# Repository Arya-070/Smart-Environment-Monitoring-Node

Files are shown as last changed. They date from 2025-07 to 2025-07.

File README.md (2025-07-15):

# 🌿 Smart Environment Monitoring Node  
📡 ESP32-WROOM-32 + LoRa + BME280 + OLED | USB Powered | Custom PCB

──────────────────────────────────────────────

## 📌 Overview

This project is a compact, power-efficient, and long-range **environment monitoring system** based on the **ESP32-WROOM-32 chip**. It measures temperature, humidity, and pressure using the **BME280 sensor**, displays real-time values on a **0.96” OLED display**, and transmits the data via **LoRa SX1262** for remote monitoring.  

All hardware is designed on a **custom 2-layer PCB** and powered via a **USB Micro-B port**, with built-in USB-to-Serial conversion and auto-upload support for seamless firmware flashing.

---

## ✨ Project Highlights

• 🔧 Fully custom-designed PCB (2-layer) using KiCad  
• 📡 Long-range LoRa communication using SX1262  
• 🌡 Environmental monitoring using BME280  
• 🖥 Local data display via 0.96” I2C OLED  
• 🔌 USB-powered with CH340C USB-to-Serial interface  
• ⏩ Auto-upload circuit using NPN transistors  
• 🔁 Reset + Boot buttons like ESP32 Dev board  
• 📍Test points for VCC & GND for easy debugging  
• 🔋 AMS1117-based 3.3V regulator (if needed)  

---

## 📌  ESP32 GPIO Pinout & Connections 

| GPIO Pin | Connected To | Function / Role |
|---|---|---|
| GPIO 0 | Q2 (Transistor) | BOOT (Auto Upload via DTR) |
| GPIO 1 (TXD)| CH340C RXD | UART Transmission |
| GPIO 3 (RXD)| CH340C TXD | UART Reception |
| GPIO 4 | SX1262 NSS | SPI Chip Select (LoRa) |
| GPIO 5 | SX1262 BUSY | LoRa Busy Status |
| GPIO 14 | SX1262 SCK | SPI Clock |
| GPIO 18 | SX1262 MISO | SPI MISO |
| GPIO 19 | SX1262 MOSI | SPI MOSI |
| GPIO 21 | OLED SDA | I2C Data (Display) |
| GPIO 22 | OLED SCL | I2C Clock (Display) |
| GPIO EN | Q1 (Transistor) | EN (Auto Reset via RTS) |
| GPIO 23 | SX1262 DIO1 | LoRa Interrupt |
| GPIO 16 | SX1262 DIO2 | LoRa General-Purpose I/O |
| GPIO 17 | BME280 SCK | SPI Clock (Sensor) |
| GPIO 2 | LED (Optional) | Debug LED Output |
| GPIO 13 | SX1262 NSS (2nd) | SPI Slave Select (Alt, Unused?) |
| GPIO 12,15 | — | Reserved / Available for future use |

🔍 *See schematic for exact net labels and detailed mapping.*

---

## 🔍 Use Case Acknowledgement

This project is ideal for:

• Agricultural field condition monitoring  
• Weather stations (indoor or outdoor)  
• Smart home environmental logging  
• Educational IoT demonstrations  
• Smart city sensor node deployment  
• Remote sensing with LoRa infrastructure

---

## 🧭 System Architecture

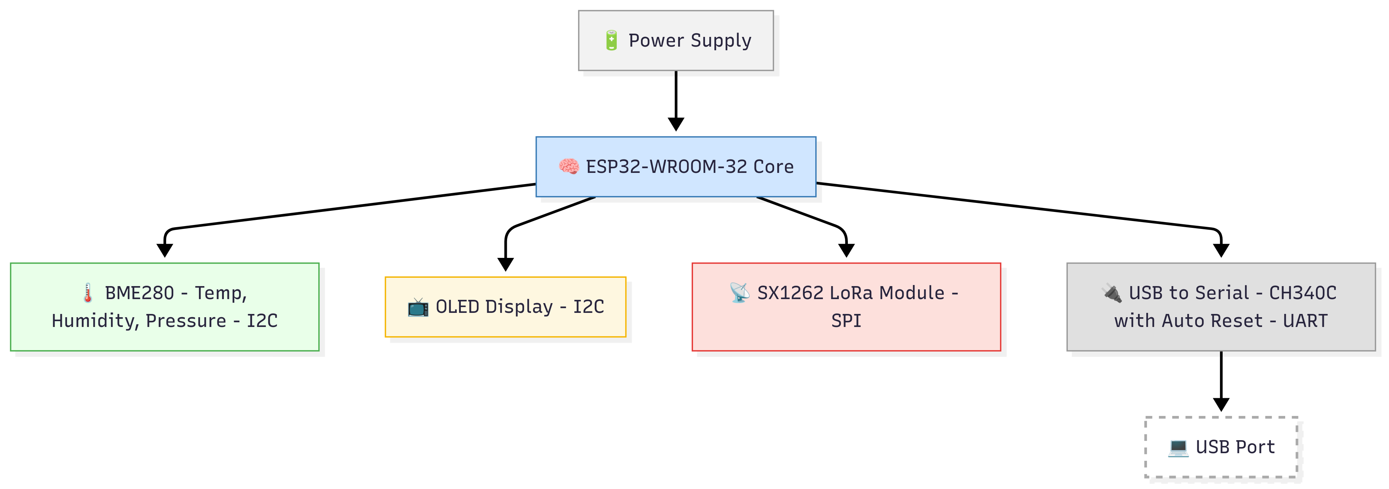
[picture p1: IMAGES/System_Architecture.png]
System Architecture


---

## 🧩 Component Summary

| No. | Component | Interface | Description |
|-----|---|---|---|
| 1 | ESP32-WROOM-32 | - | Main MCU (WiFi, BLE, Dual Core) |
| 2 | BME280 (SPI) | SPI | Temp, Pressure, Humidity sensor |
| 3 | OLED 0.96” Display | I2C | SSD1306, 128x64 pixel display |
| 4 | SX1262IMLTRT (QFN) | SPI | LoRa transceiver (433/868/915MHz) |
| 5 | AMS1117-3.3V Regulator | Power | Converts 5V USB to 3.3V (optional) |
| 6 | CH340C USB to Serial | UART | USB programming interface |
| 7 | 40MHz Crystal Oscillator| CLK | ESP32 clock source |
| 8 | Push Buttons (2x) | GPIO/EN | Boot and Reset functionality |
| 9 | LED + Resistor | Power | Power-on indicator |
| 10  | Capacitors (0.1µF, 10µF)| Power | Decoupling & filtering |
| 11  | Test Points (TP1/TP2)  | - | For debugging (3.3V and GND) |
| 12  | Micro USB Port | Power | Power + Serial communication |
| 13  | Resistors (10k, 1k) | Logic | Pull-ups and transistor base resistors |
| 14  | NPN Transistors (x2) | Auto Upload | Connected to DTR/RTS |
| 15  | Conn_01x2 / 01x4 / 01x8| Header | GPIO/I2C/Power breakout (optional) |

---

## 💾 Firmware Summary

• Platform: Arduino Framework  
• Libraries:
  - `Adafruit_BME280` (SPI)
  - `U8g2lib` / `Adafruit_SSD1306`
  - `RadioLib` or `LoRa` for SX1262
• Logic:
  - Read sensor values → Display on OLED → Send via LoRa
• Auto-upload handled via CH340C + transistor toggling of IO0 and EN

---

## 🧪 Test Points

| Label | Connected To | Use |
|---|---|---|
| TP1 | 3.3V | Voltage test/debug |
| TP2 | GND | Ground continuity check |

---

## 📦 Folder Structure

```
Smart-Environment-Monitoring-Node/
│
├── SCHEMATIC/
│   ├── Smart_Env_monitoring_Node.kicad_sch
│   ├── Smart_Env_monitoring_Node.pdf
│  
├── Backup_ZIP
│
├── PCB/
│   ├──  Smart_Env_monitoring_Node.kicad_pcb
│   ├──  Smart_Env_monitoring_Node.kicad_pro
│   ├──  Smart_Env_monitoring_Node.csv
│   ├── Gerber_Files/
│   ├── F_Cu.gbr
│   ├── B_Cu.gbr
│   ├── Edge_Cuts.gbr
│   ├── Drill.drl
│   └── ...etc
│
├── Firmware/
│   └── main.ino 
│
├── Libraries/
│   ├── COMPONENTS_DOWNLOADED/
│   └── MY_LIBRARY_MODIFIED.pretty/
│
├── Images/
│   ├── 3D_View.png
│   ├── Top_Layout.png
│   ├── Bottom_Layout.png
│   └── System_Architecture.png
│
├── README.md
└── .gitignore
```

---

## 📐 PCB Design Summary

• Software: KiCad 7.0  
• Layers: 2 (Top & Bottom)  
• Antenna zone: Keep-out area maintained  
• Crystal zone: No trace below (as per layout best practices)  
• Ground pour: Yes, with via stitching  
• Auto-upload near CH340C  
• I2C lines shared between OLED and future I2C sensors

---

## 📌 Optional Headers

| Header | Size | Description |
|---|---|---|
| Conn_01x2  | 2-pin | External battery connection |
| Conn_01x4  | 4-pin | I2C expansion header |
| Conn_01x8  | 8-pin | GPIO access (debug/expansion) |

---

## 🔮 Future Improvements

• Add onboard Li-ion battery charging (TP4056)  
• Use low-dropout regulator instead of AMS1117  
• Enable I2C/SPI switch for BME280  
• Add buzzer or notification LED  
• Add deep sleep mode for power efficiency  
• Add mobile enclosure + mounting holes

---

## 📜 License

Licensed under the MIT License.  
Feel free to use, modify, and share — just give credit. 

---

## 🤝 Acknowledgements

This project is inspired by real-world smart sensing requirements and open hardware communities. Thanks to Espressif Systems, Adafruit, and the KiCad team for empowering makers with tools and documentation.

---

## 📬 Contact / Contribution

• Found something useful? Leave a ⭐ on GitHub.  
• Found a bug or want to improve? Fork and PRs are welcome.  
• Reach out for collaboration or questions!

Let’s make sensing smarter, together. 🌍

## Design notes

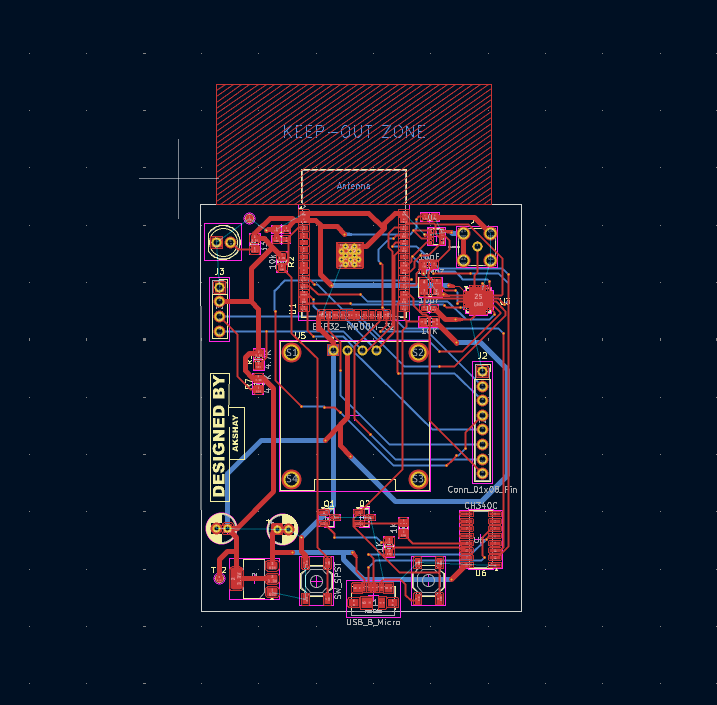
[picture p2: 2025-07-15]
IMAGES/editor-view.png

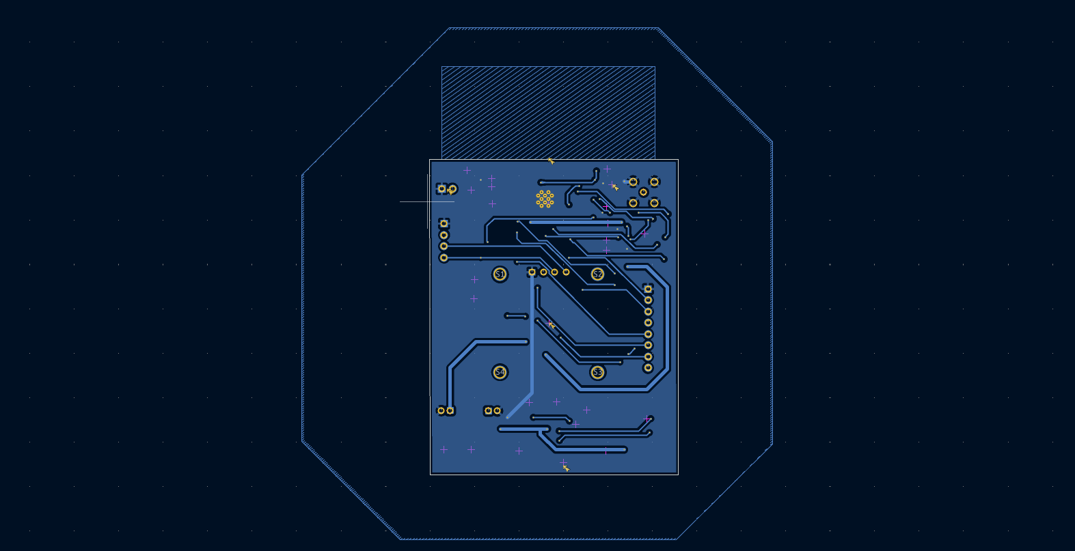
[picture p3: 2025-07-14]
IMAGES/Bottom_Layout.png

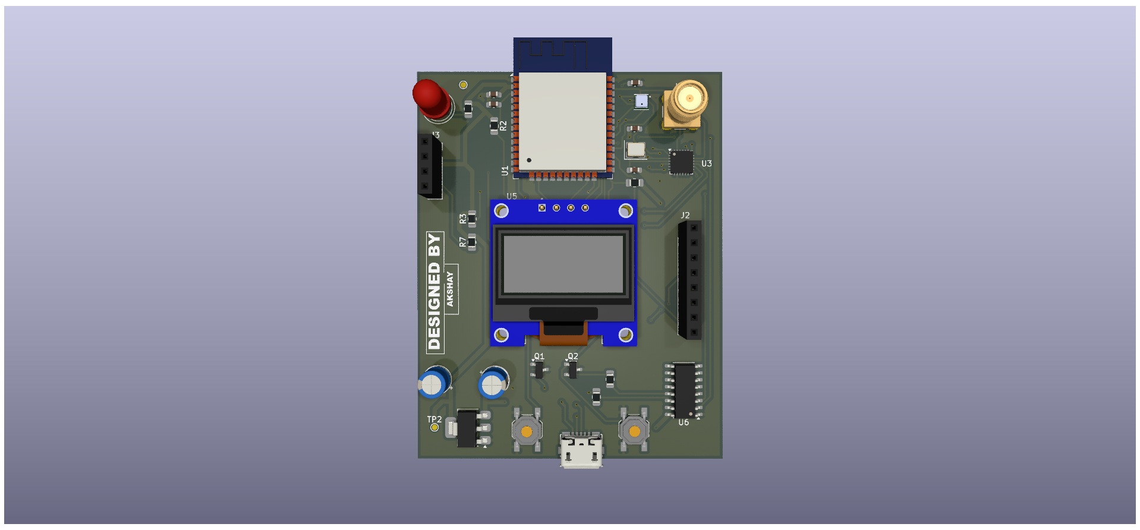
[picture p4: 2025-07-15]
IMAGES/3d-View.png

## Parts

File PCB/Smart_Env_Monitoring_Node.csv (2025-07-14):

Reference | Qty | Value | DNP | Exclude from BOM | Exclude from Board | Footprint | Datasheet
C1,C2 | 2 | 10uF |  |  |  | Capacitor_THT:CP_Radial_D5.0mm_P2.00mm | ~
C3,C4,C5 | 3 | 0.1uF |  |  |  | Capacitor_SMD:C_0603_1608Metric_Pad1.08x0.95mm_HandSolder | ~
C6,C7 | 2 | 10pF |  |  |  | Capacitor_SMD:C_0603_1608Metric_Pad1.08x0.95mm_HandSolder | ~
D1 | 1 | LED |  |  |  | MY_LIBRARY_MODIFIED:LED_D5.0mm_modified | ~
J1 | 1 | USB_B_Micro |  |  |  | MY_LIBRARY_MODIFIED:USB_Micro-B_Molex_47346-0001 | ~
J2 | 1 | Conn_01x08_Pin |  |  |  | Connector_PinSocket_2.54mm:PinSocket_1x08_P2.54mm_Vertical | ~
J3 | 1 | Conn_01x04_Pin |  |  |  | Connector_PinSocket_2.54mm:PinSocket_1x04_P2.54mm_Vertical | ~
J4 | 1 | SMA_CONNECTOR |  |  |  | SMA_FEMALE:LPRS_SMA_CONNECTOR
Q1,Q2 | 2 | BC547 |  |  |  | Package_TO_SOT_SMD:SOT-23 | ~
R1 | 1 | 10K |  |  |  | Resistor_SMD:R_0805_2012Metric_Pad1.20x1.40mm_HandSolder | ~
R2 | 1 | 10k |  |  |  | Resistor_SMD:R_0805_2012Metric_Pad1.20x1.40mm_HandSolder | ~
R3,R7 | 2 | 4.7K |  |  |  | Resistor_SMD:R_0805_2012Metric_Pad1.20x1.40mm_HandSolder | ~
R4 | 1 | 330 |  |  |  | Resistor_SMD:R_0805_2012Metric_Pad1.20x1.40mm_HandSolder | ~
R5,R6 | 2 | 1K |  |  |  | Resistor_SMD:R_0805_2012Metric_Pad1.20x1.40mm_HandSolder | ~
SW2,SW3 | 2 | SW_SPST |  |  |  | Button_Switch_SMD:SW_SPST_TL3342 | ~
TP1,TP2 | 2 | TestPoint |  |  |  | TestPoint:TestPoint_Pad_D1.0mm | ~
U1 | 1 | ESP32-WROOM-32 |  |  |  | MY_LIBRARY_MODIFIED:ESP32-WROOM-32_MODIFIED | https://www.espressif.com/sites/default/files/documentation/esp32-wroom-32_datasheet_en.pdf
U2 | 1 | AMS1117-3.3 |  |  |  | Package_TO_SOT_SMD:SOT-223-3_TabPin2 | http://www.advanced-monolithic.com/pdf/ds1117.pdf
U3 | 1 | SX1262IMLTRT |  |  |  | Package_DFN_QFN:QFN-24-1EP_4x4mm_P0.5mm_EP2.6x2.6mm | https://semtech.file.force.com/sfc/dist/version/download/?oid=00DE0000000JelG&ids=0682R00000IjPWSQA3
U4 | 1 | BME280 |  |  |  | BME280:PSON65P250X250X100-8N
U5 | 1 | DM-OLED096-636 |  |  |  | DM-OLED096-636:MODULE_DM-OLED096-636
U6 | 1 | CH340C |  |  |  | Package_SO:SOIC-16_3.9x9.9mm_P1.27mm | https://datasheet.lcsc.com/szlcsc/Jiangsu-Qin-Heng-CH340C_C84681.pdf
Y1 | 1 | 16Mhz |  |  |  | Crystal:Crystal_SMD_3225-4Pin_3.2x2.5mm | ~

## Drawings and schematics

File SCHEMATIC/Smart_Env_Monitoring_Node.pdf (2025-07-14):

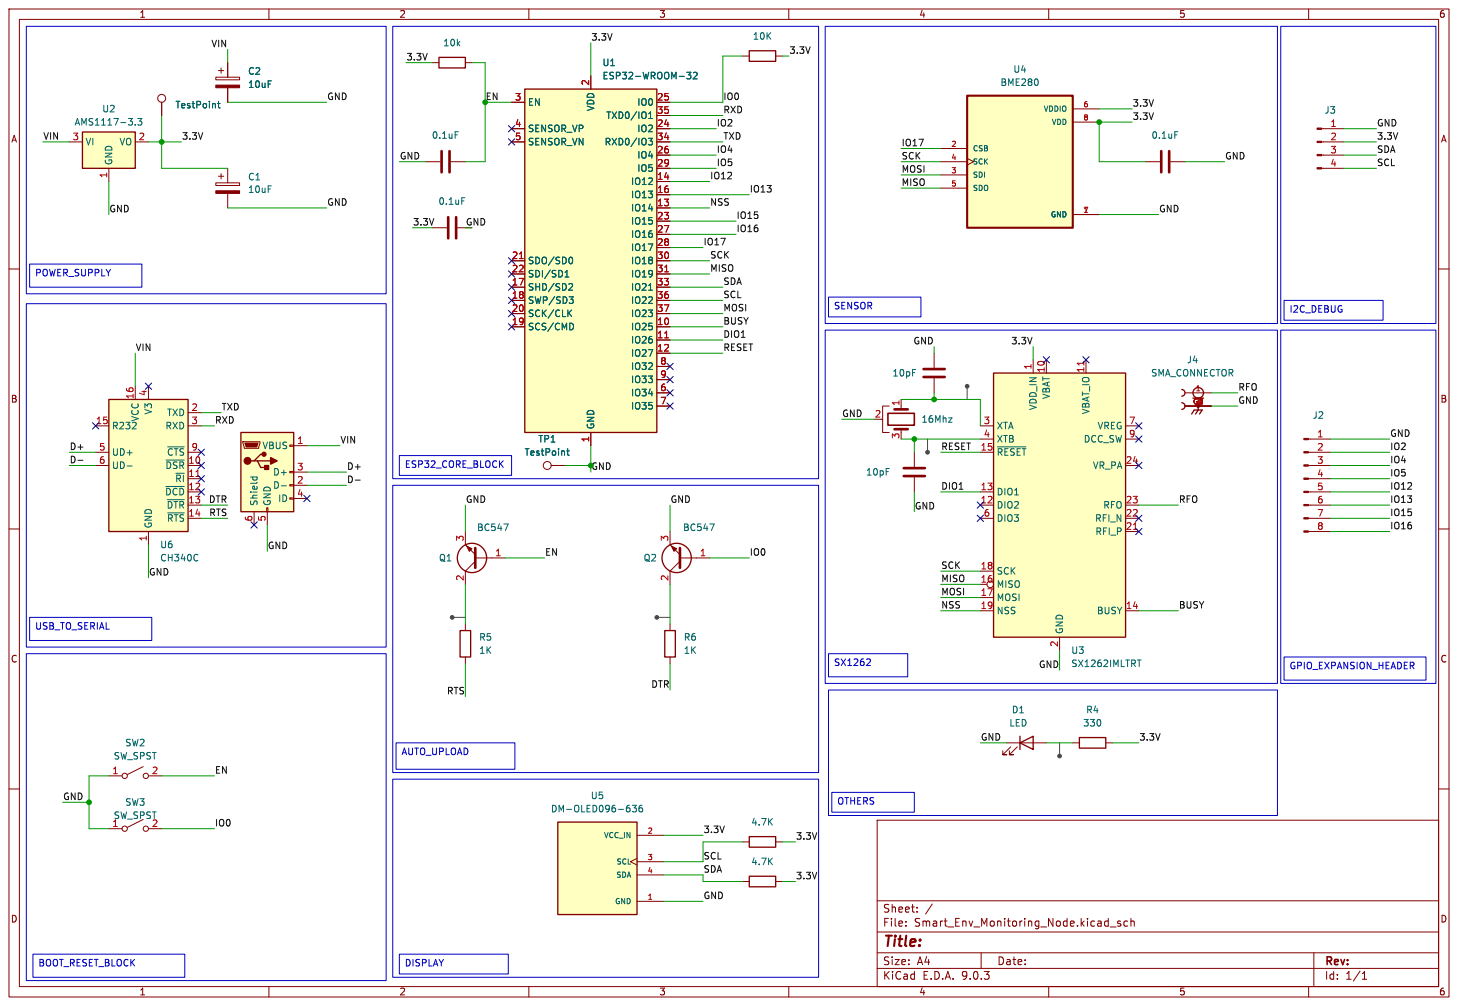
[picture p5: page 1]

1 TXD 2 RXD 3 ~{CTS}9 ~{DSR} 10 ~{RI} 11 ~{DCD} 12 ~{DTR} 13 ~{RTS} 14 U6 CH340C Shield

Id: 1/1 Title: File: Smart_Env_Monitoring_Node.kicad_sch Sheet: /

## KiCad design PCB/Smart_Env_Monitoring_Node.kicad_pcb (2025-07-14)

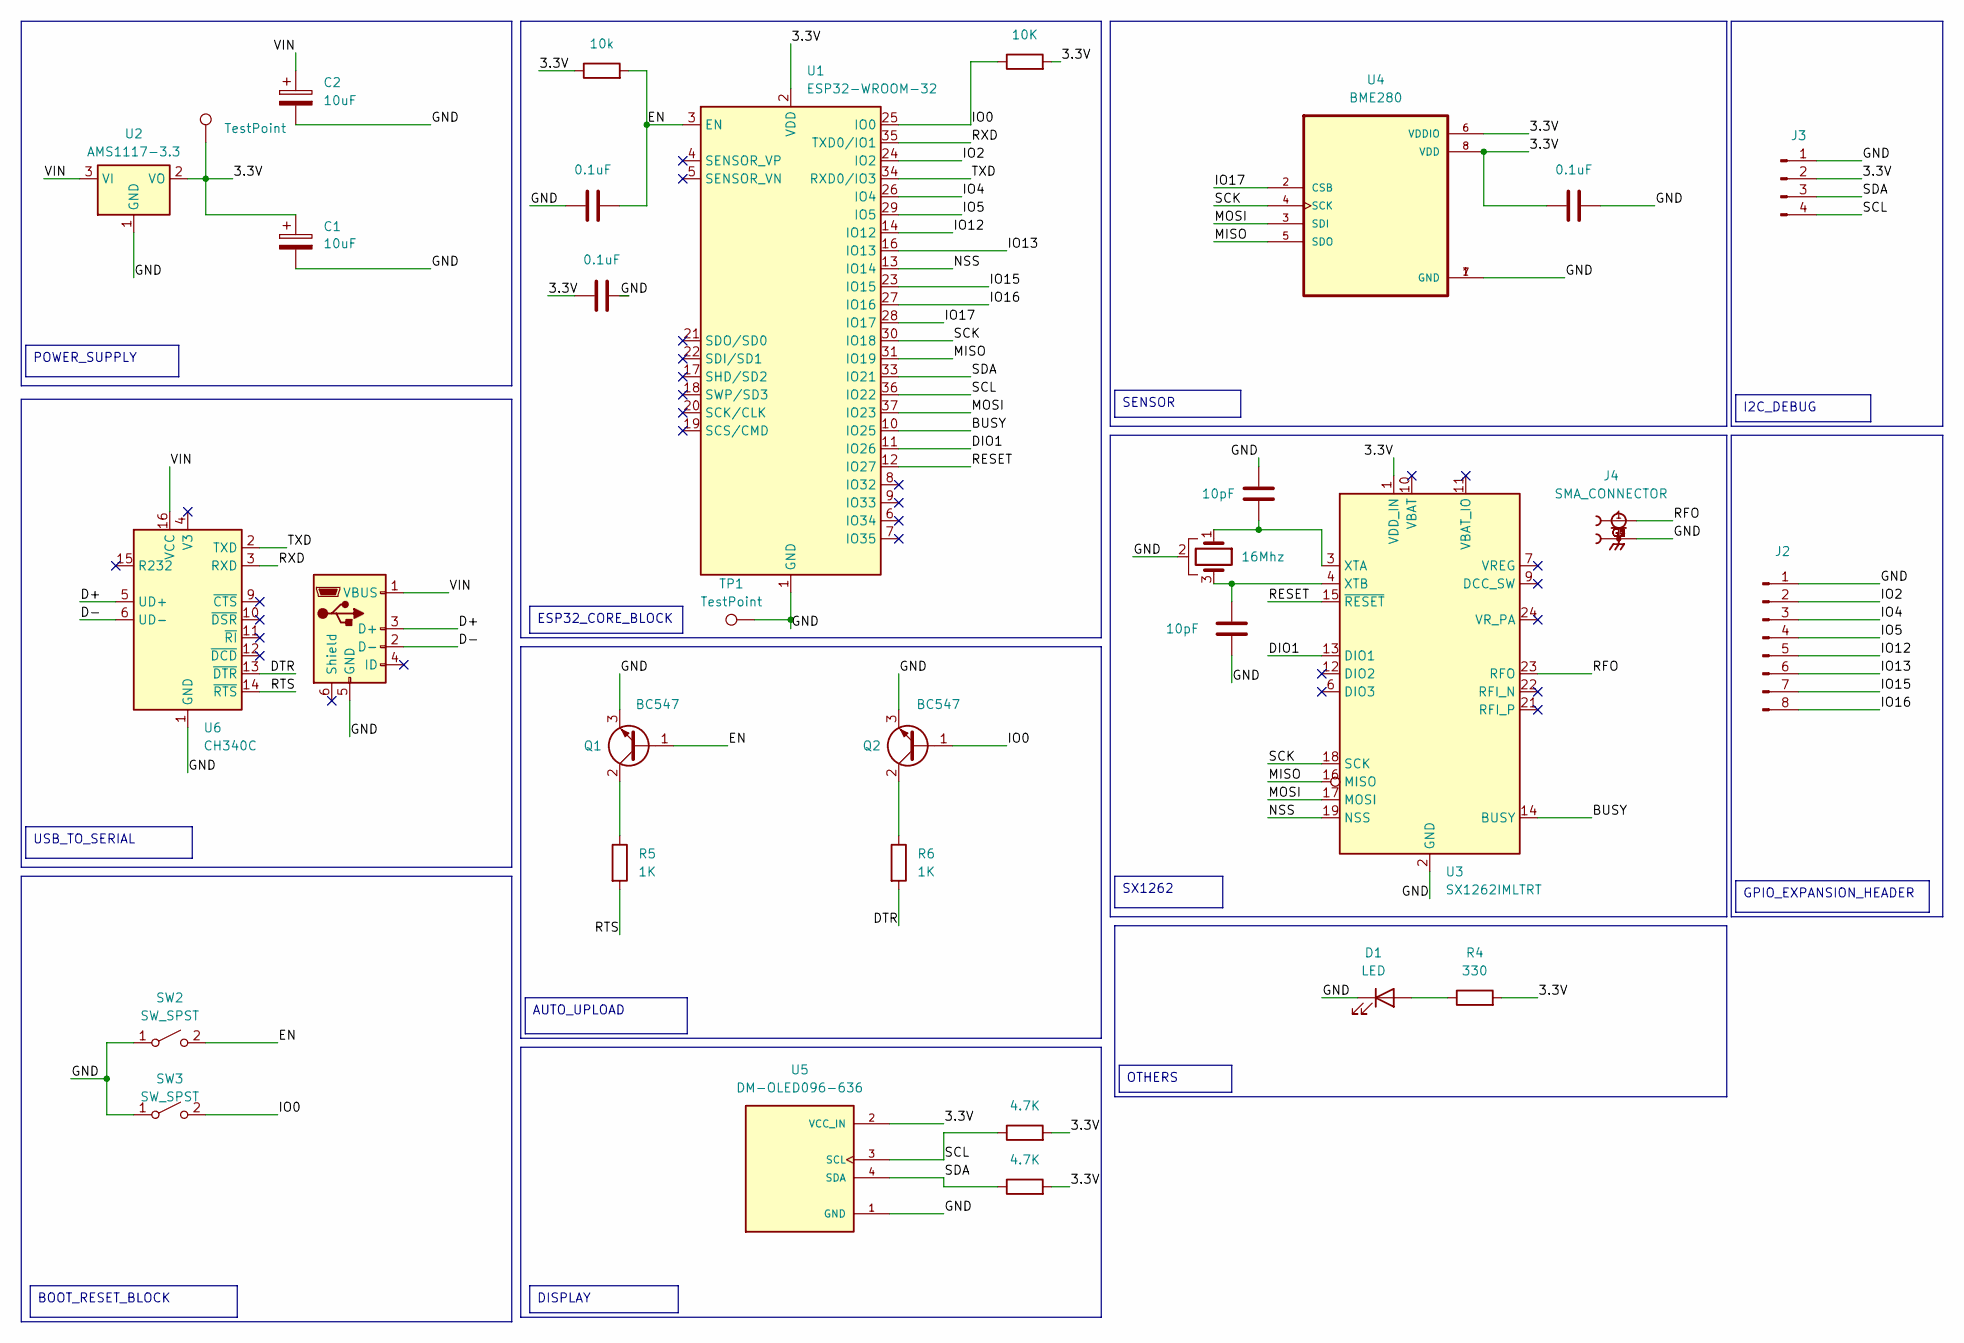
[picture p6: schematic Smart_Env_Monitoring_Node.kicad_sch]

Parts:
C1, C2: 10uF; CP_Radial_D5.0mm_P2.00mm
C3, C4, C5: 0.1uF; C_0603_1608Metric_Pad1.08x0.95mm_HandSolder
C6, C7: 10pF; C_0603_1608Metric_Pad1.08x0.95mm_HandSolder
D1: LED; LED_D5.0mm_modified
J1: USB_B_Micro; USB_Micro-B_Molex_47346-0001
J2: Conn_01x08_Pin; PinSocket_1x08_P2.54mm_Vertical
J3: Conn_01x04_Pin; PinSocket_1x04_P2.54mm_Vertical
J4: SMA_CONNECTOR; LPRS_SMA_CONNECTOR; PARTREV 1.3
Q1, Q2: BC547; SOT-23
R1: 10K; R_0805_2012Metric_Pad1.20x1.40mm_HandSolder
R2: 10k; R_0805_2012Metric_Pad1.20x1.40mm_HandSolder
R3, R7: 4.7K; R_0805_2012Metric_Pad1.20x1.40mm_HandSolder
R4: 330; R_0805_2012Metric_Pad1.20x1.40mm_HandSolder
R5, R6: 1K; R_0805_2012Metric_Pad1.20x1.40mm_HandSolder
SW2, SW3: SW_SPST; SW_SPST_TL3342
TP1, TP2: TestPoint; TestPoint_Pad_D1.0mm
U1: ESP32-WROOM-32; ESP32-WROOM-32_MODIFIED
U2: AMS1117-3.3; SOT-223-3_TabPin2
U3: SX1262IMLTRT; QFN-24-1EP_4x4mm_P0.5mm_EP2.6x2.6mm
U4: BME280; PSON65P250X250X100-8N
U5: DM-OLED096-636; MODULE_DM-OLED096-636; PARTREV 2018-09-10
U6: CH340C; SOIC-16_3.9x9.9mm_P1.27mm
Y1: 16Mhz; Crystal_SMD_3225-4Pin_3.2x2.5mm

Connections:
/3.3V: C1.1, C4.1, C5.1, J3.2, R1.2, R2.1, R3.2, R4.2, R7.2, TP2.1, U1.2 (VDD), U2.2 (VO), U3.1 (VDD_IN), U4.6 (VDDIO), U4.8 (VDD), U5.2 (VCC_IN)
/BUSY: U1.10 (IO25), U3.14 (BUSY)
/D+: J1.3 (D+), U6.5 (UD+)
/D-: J1.2 (D-), U6.6 (UD-)
/DIO1: U1.11 (IO26), U3.13 (DIO1)
/DTR: R6.2, U6.13 (~DTR)
/EN: C3.2, Q1.1 (B), R2.2, SW2.2 (B), U1.3 (EN)
/GND: C1.2, C2.2, C3.1, C4.2, C5.2, C6.1, C7.2, D1.1 (K), J1.5 (GND), J2.1, J3.1, J4.G1, J4.G2, J4.G3, J4.G4, Q1.3 (E), Q2.3 (E), SW2.1 (A), SW3.1 (A), TP1.1, U1.1 (GND), U1.15 (GND), U1.38 (GND), U1.39 (GND), U2.1 (GND), U3.2 (GND), U3.5 (GND), U3.8 (GND), U3.20 (GND), U3.25 (GND), U4.1 (GND), U4.7 (GND), U5.1 (GND), U6.1 (GND), Y1.2
/IO0: Q2.1 (B), R1.1, SW3.2 (B), U1.25 (IO0)
/IO2: J2.2, U1.24 (IO2)
/IO4: J2.3, U1.26 (IO4)
/IO5: J2.4, U1.29 (IO5)
/IO12: J2.5, U1.14 (IO12)
/IO13: J2.6, U1.16 (IO13)
/IO15: J2.7, U1.23 (IO15)
/IO16: J2.8, U1.27 (IO16)
/IO17: U1.28 (IO17), U4.2 (CSB)
/MISO: U1.31 (IO19), U3.16 (MISO), U4.5 (SDO)
/MOSI: U1.37 (IO23), U3.17 (MOSI), U4.3 (SDI)
/NSS: U1.13 (IO14), U3.19 (NSS)
/RESET: U1.12 (IO27), U3.15 (~RESET)
/RFO: J4.1, U3.23 (RFO)
/RTS: R5.2, U6.14 (~RTS)
/RXD: U1.35 (TXD0/IO1), U6.3 (RXD)
/SCK: U1.30 (IO18), U3.18 (SCK), U4.4 (SCK)
/SCL: J3.4, R3.1, U1.36 (IO22), U5.3 (SCL)
/SDA: J3.3, R7.1, U1.33 (IO21), U5.4 (SDA)
/TXD: U1.34 (RXD0/IO3), U6.2 (TXD)
/VIN: C2.1, J1.1 (VBUS), U2.3 (VI), U6.16 (VCC)
unnamed: D1.2 (A), R4.1
unnamed: Q1.2 (C), R5.1
unnamed: Q2.2 (C), R6.1
unnamed: C6.2, U3.3 (XTA), Y1.1
unnamed: C7.1, U3.4 (XTB), Y1.3

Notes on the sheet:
GPIO_EXPANSION_HEADER
OTHERS
BOOT_RESET_BLOCK
SX1262
USB_TO_SERIAL
SENSOR
ESP32_CORE_BLOCK
DISPLAY
I2C_DEBUG
POWER_SUPPLY
AUTO_UPLOAD

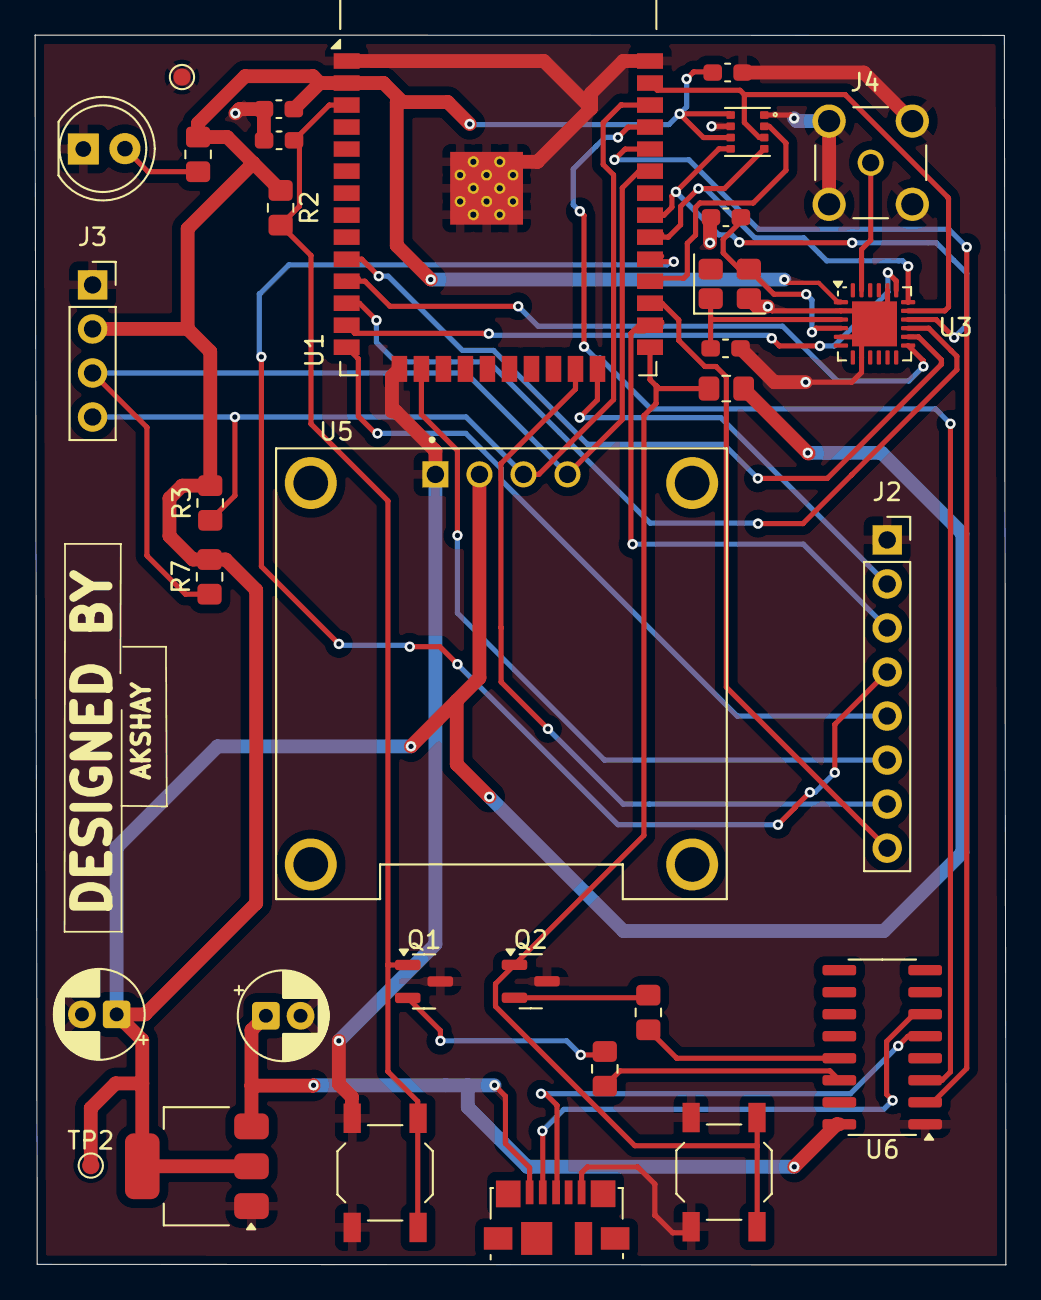
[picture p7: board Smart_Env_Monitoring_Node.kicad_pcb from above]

Board: 2 copper layers, 56.0 x 70.9 mm, 32 parts (0 on the bottom side), 34 nets.

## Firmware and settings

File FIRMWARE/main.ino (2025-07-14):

#include <Wire.h>
#include <SPI.h>
#include <Adafruit_GFX.h>
#include <Adafruit_SSD1306.h>
#include <Adafruit_BME280.h>
#include <LoRa.h>

// ---------------------------
// OLED Display Configuration
// ---------------------------
#define SCREEN_WIDTH 128
#define SCREEN_HEIGHT 64
#define OLED_SDA 22
#define OLED_SCL 21
#define OLED_RESET -1
Adafruit_SSD1306 display(SCREEN_WIDTH, SCREEN_HEIGHT, &Wire, OLED_RESET);

// ---------------------------
// BME280 Configuration (SPI)
// ---------------------------
#define BME_CS   17
#define BME_SCK  18
#define BME_MOSI 23
#define BME_MISO 19
Adafruit_BME280 bme(BME_CS, BME_MOSI, BME_MISO, BME_SCK);

// ---------------------------
// LoRa SX1262 Configuration
// ---------------------------
#define LORA_CS   5
#define LORA_RST  14
#define LORA_BUSY 15
#define LORA_SCK  18
#define LORA_MISO 19
#define LORA_MOSI 23
#define LORA_FREQ 868E6  // Adjust based on your region

void setup() {
  Serial.begin(9600);
  delay(1000);
  Serial.println("Smart Environment Monitoring Node");

  // ---------------------------
  // Initialize OLED
  // ---------------------------
  Wire.begin(OLED_SDA, OLED_SCL);
  if (!display.begin(SSD1306_SWITCHCAPVCC, 0x3C)) {
    Serial.println(F("OLED init failed"));
    while (true);
  }
  display.clearDisplay();
  display.setTextSize(1);
  display.setTextColor(SSD1306_WHITE);

  // ---------------------------
  // Initialize BME280
  // ---------------------------
  if (!bme.begin()) {
    Serial.println("Could not find BME280 sensor!");
    while (1);
  }
  Serial.println("BME280 Sensor Ready");

  // ---------------------------
  // Initialize LoRa (SX1262)
  // ---------------------------
  SPI.begin(LORA_SCK, LORA_MISO, LORA_MOSI, LORA_CS);
  LoRa.setPins(LORA_CS, LORA_RST, LORA_BUSY);

  if (!LoRa.begin(LORA_FREQ)) {
    Serial.println("Starting LoRa failed!");
    while (1);
  }
  Serial.println("LoRa SX1262 Ready");
}

void loop() {
  // Read sensor data
  float temperature = bme.readTemperature();
  float humidity = bme.readHumidity();
  float pressure = bme.readPressure() / 100.0F;

  // Display on OLED
  display.clearDisplay();
  display.setCursor(0, 0);
  display.println("Smart Env Node");
  display.print("Temp: "); display.print(temperature); display.println(" C");
  display.print("Hum: "); display.print(humidity); display.println(" %");
  display.print("Pres: "); display.print(pressure); display.println(" hPa");
  display.display();

  // Send via LoRa
  LoRa.beginPacket();
  LoRa.print("T:"); LoRa.print(temperature);
  LoRa.print(" H:"); LoRa.print(humidity);
  LoRa.print(" P:"); LoRa.print(pressure);
  LoRa.endPacket();

  Serial.println("Data Sent via LoRa");
  delay(5000);  
}

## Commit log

2025-07-14 Initial commit: Added full Smart Environment Monitoring Node project
    [Smart_Env_Monitoring_Node-B_Cu.gbr, Smart_Env_Monitoring_Node-B_Mask.gbr, Smart_Env_Monitoring_Node-B_Paste.gbr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]
2025-07-14 Update and rename Smart_Env_Monitoring_Node.kicad_sch.kicad_sch to Smart_Env_Monitoring_Node.kicad_sch
    [Smart_Env_Monitoring_Node.kicad_sch]
2025-07-14 Update and rename Smart_Env_Monitoring_Node.kicad_pcb.kicad_pcb to Smart_Env_Monitoring_Node.kicad_pcb
    [Smart_Env_Monitoring_Node.kicad_pcb]
